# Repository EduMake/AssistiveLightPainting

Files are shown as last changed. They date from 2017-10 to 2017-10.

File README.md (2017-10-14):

# AssistiveLightPainting

Using SVG drawings to make light paintings using a custom large RGB light based non-orthongal plotter.

## Do you want to make videos like this ???

Lichtfactor - Talk Talk Advert (https://www.youtube.com/watch?v=QoT53RirX0Y)

## But physically moving a light quickly is difficult for you?

We are building a system to help. It will allow you to animate on your laptop and have a mechansism do the physical moving of the lights.

This uses the following technologies:-
 - Raspberry Pi
 - Adafruit Stepper Motor HAT https://www.adafruit.com/product/2348
 - SVG [Scalable Vector Graphics](https://en.wikipedia.org/wiki/Scalable_Vector_Graphics)
 - http://anigen.org/versions/0_8_1/
 - https://shop.pimoroni.com/products/mote
 - Out version of vPiP   https://github.com/EduMake/vPiP

## System Layout

You will prepare the animation and at shooting time set up a frame (we are prototyping with a 2.5m x 4m Chromakey background frame). Attach our vPlotter mounts, beaded cord and lights. 

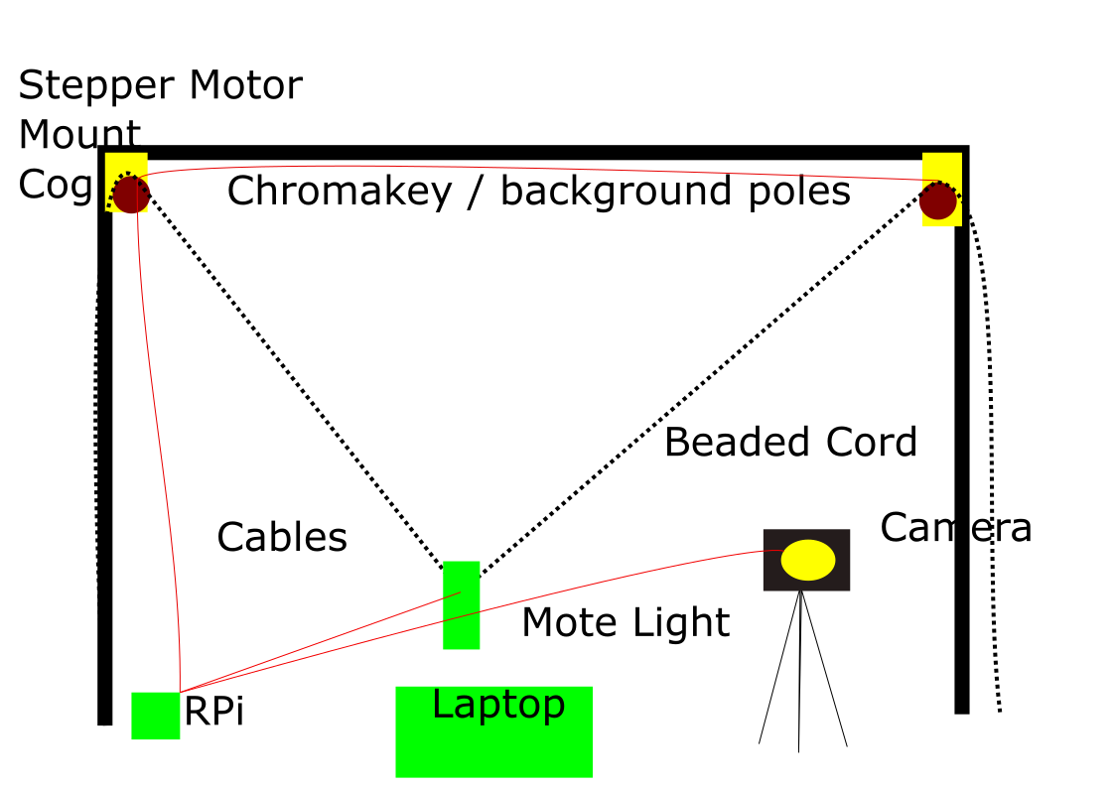
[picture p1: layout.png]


## Our custon vPlotter Mount

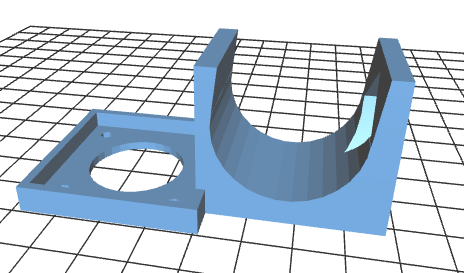
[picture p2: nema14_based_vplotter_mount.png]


### Currently in Development.

## The Proposed Process

- Install our software and hardware on a raspberry pi
- Use SVG editing software to draw your characters 
  - [inkscape](https://inkscape.org/en/) 
  - [SVG Edit](https://svg-edit.github.io/svgedit/releases/svg-edit-2.8.1/svg-editor.html)
  - [Vector Paint](http://vectorpaint.yaks.co.nz/)
  - [Drawing SVG](http://drawsvg.org/drawsvg.html)
- Use inkscape etc. to layout your scenes 
- Use Anigen to animate those scenes http://anigen.org/versions/0_8_1/
  - Line colours and widths should be picked up by the lights on the vplotter
- Export the animation as zip file of indvidual frames
- Set up our custom, large format light v-plotter, using our parts and a frame.
- Set up camera and raspberry pi control box
- Run through setup procedure in software
- Using your laptop / tablet / phone you will then trigger each frame to be lightpainted whilst the camera takes the shot
- The images are then compiled into a movie file.

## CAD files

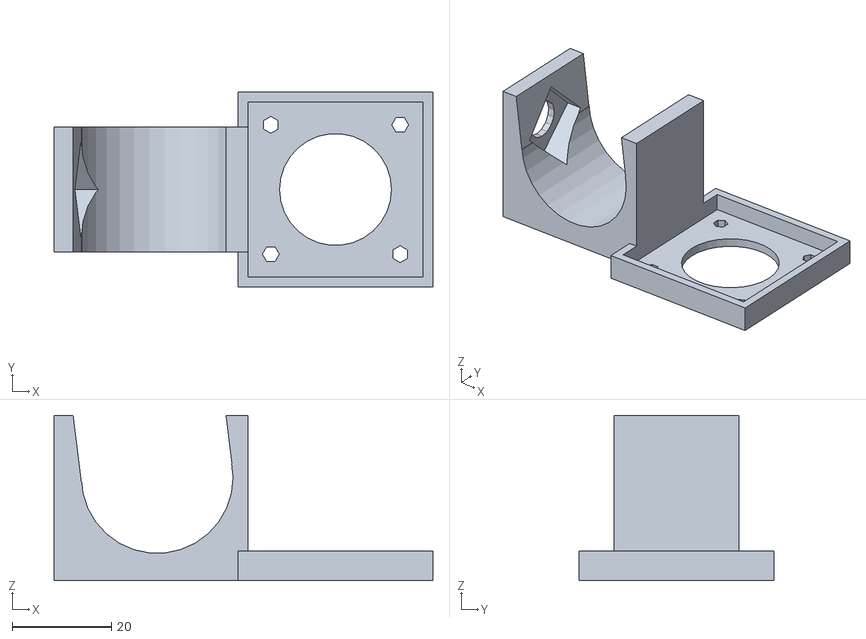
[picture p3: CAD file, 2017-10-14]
nema14_based_vplotter_mount.stl
76.2 x 39.2 x 33.2

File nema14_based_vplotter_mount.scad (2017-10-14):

//nema mount
nema_width      = 35.2;
nema_screw_dist = 26;
nema_screw_dia  = 3.4;
nema_indent_dia = 22.5;
plate_thickness = 2;
wall_height     = 6;

plate_width     = nema_width+(plate_thickness*2);
 
tube_dia        = 30.5;
clamp_inner      = 3;
clamp_outer      = 5.5;
nut_width = 13.5;
nut_depth = 3.5;
bolt_dia  = 9;


clamp_length     = (nut_width*sqrt(2))+(2*clamp_inner);//plate_width;
clamp_width = tube_dia+ clamp_inner + clamp_outer ;

clamp_height    = tube_dia+(clamp_outer*2);//clamp_width;//30;




union(){
    //nema plate
    translate([plate_width/2,0,wall_height/2]){
        difference(){
            
            cube([plate_width, plate_width, wall_height],center=true);
            
            translate([0,0,2]){
                cube([nema_width, nema_width,wall_height],center=true);
            }
            
            cylinder(r=nema_indent_dia/2,h=wall_height, center=true);
            
            
            for(angle = [0:90:300]){
                rotate(a = angle){
                    translate([nema_screw_dist/2,nema_screw_dist/2,0]){
                        cylinder(r=nema_screw_dia/2,h=wall_height, center=true);
                    }
                }
            }
        }
    }

    
    //clamp
    translate([plate_thickness -(clamp_width/2), 0, clamp_height/2]){
        
        difference(){        
            cube([clamp_width, clamp_length, clamp_height], center=true);
            translate([(clamp_outer-clamp_inner)/2,0,0]){
            rotate([90, 0, 0]){
                cylinder(r=tube_dia/2, h=plate_width, center=true);
            }
            
            rotate([0, -7, 0]){
            translate([0, 0, tube_dia*0.53]){
                
                    cube([tube_dia
                , clamp_width, tube_dia], center=true);
                }
            }
        
            //Captive nut
            translate([ -(tube_dia/2
        ), 0,0]){
                rotate([45,0,0]){
                    cube([nut_depth*2.2, nut_width,  nut_width], center=true);
                }
                rotate([0,90,0]){     
                    cylinder(r=bolt_dia/2,h=clamp_outer*3, center=true);
                }
            }
        }
            translate([0, 0, clamp_outer+(tube_dia/2)]){
                cube([clamp_width, clamp_height, clamp_outer*3], center=true);
            }
        
    }
    }
}

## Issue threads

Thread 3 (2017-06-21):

V-Plotter hardware

stretchyboy, 2017-06-21:
- http://homofaciens.de/technics-machines-v-plotter_en.htm
- http://www.open-electronics.org/how-to-make-an-opensource-vertical-plotter/
- http://polargraph.bigcartel.com/  especially the sprockets & beaded cord

Stepper Drivers

https://shop.pimoroni.com/products/adafruit-dc-stepper-motor-hat-for-raspberry-pi-mini-kit
https://shop.pimoroni.com/products/pistep2-quad-stepper-motor-control-board-for-raspberry-pi

stretchyboy, 2017-06-21:
- https://github.com/MarkJB/pi-zero-stepper-board

stretchyboy, 2017-06-21:
Motor mount and cog thing to modify to fit on the lighting poles https://www.thingiverse.com/thing:1393164

stretchyboy, 2017-06-21:
Lighting stand mount features

First, a 3/8-16 UNC thread (that's 3/8", 16 threads per inch). This is, fortunately, basically standardized in all such gear.

Second, a 5/8" stud, usually meant for clamping things to, or often attaching things via a socket with a screw on the side. This socket is often called a "receiver" or "receptor" — useful to know if you're searching.

Since the second connection type is less critical than matching threads, the precise size may vary — I've also often seem this described as a "16mm stud", which is very close to 5/8" but of course not identical. (And, yes, we're generally cavalier about mixing metric and imperial in photography — a so-called 1" sensor has a diagonal of 16mm, to pick another example.)

In many cases, the studs on light stands also are threaded on top. For example, here's the top of one of mine:

stretchyboy, 2017-07-26:
Motors are http://www.zappautomation.co.uk/sy35st36-1004b-high-torque-hybrid-stepper-motors.html

stretchyboy, 2017-08-16:
https://www.thingiverse.com/thing:569308

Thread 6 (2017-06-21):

Setup technique

stretchyboy, 2017-06-21:
a reproduce-able way to make sure the set up is the same each time.

maybe :
- zoom  out enough so the the poles are parallel at the edges of the shot
- position the light at the top right of the drawing area and zoom in until it's there in the view finder

Possible verification step using drawing the rule of thirds grid using the lights to line up against the one on the screen.

stretchyboy, 2017-06-21:
Ideal version of hardware would allow it to measure itself during setup. Possible by having the gondola start at the bottom height whilst the poles are together and have it draw the gondola up until it hits a limit switch. You would then run the gondola back down on both sides. Separate the 2 poles to the distance you want and hold on to them then run both motors until a limit switch shows its horizontal. then do maths.  That should give the total dimensions. use the code ideas in #5 . images are then either scaled to the draw area or rendered at actual size.

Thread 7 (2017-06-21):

Plotter software ideas

stretchyboy, 2017-06-21:
- https://github.com/bertlr/vplotter
- https://github.com/brianinnes/vpip  https://www.makebournemouth.com/?p=947
- http://plotterbot.com/robots/plotterbot-documentation/plotterbot-prior-art/ list of projects

stretchyboy, 2017-07-27:
Most likely appears to be  https://github.com/brianinnes/vPiP

If I fork it and replace the serialHandler with one that handles the stepper hat  https://shop.pimoroni.com/products/adafruit-dc-stepper-motor-hat-for-raspberry-pi-mini-kit

And a the light and possibly camera control :)

stretchyboy, 2017-08-23:
sudo pip install webcolors

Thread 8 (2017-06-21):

Identify minimum test rig.

stretchyboy, 2017-06-21:
- [ ] get motors
- [ ] find stepper driver board
- [ ] could we mount motors with gaffer tape?
- [ ] 3d print gears to fit the motors.
- [ ] Get cord
- [ ] Mount torch or mote in middle of cord
- [ ] get driver  software just to do up & down on both motors
- [ ] Test with camera

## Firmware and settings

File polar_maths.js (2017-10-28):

var extend = require('extend');
var queue = require('queue');
var promiseify = require('promiseify');

//extend(targetObject, object1, object2);

/*can be set to calc drawing and offset  using ideas from
http://2e5.com/plotter/V/design/ so set machine size and
tell it the aspectratio (that of the camera) and it will
 maximise the effective working area
aspect_ratio :  16/9 */

var PolarMaths = module.exports = function PolarMaths(options) {
  this.q = queue({
    concurrency: 1,
    autostart: true
  });
  this.q.on('success', function(result, job) {
    //console.log('job finished processing:', job.toString().replace(/\n/g, ''))
  });

  options = options || {};

  this.dimensions_mm = {
    machine: {
      x: 4000,
      y: 2000
    },
    drawing: {
      x: 2000,
      y: 1200
    },
    offset: {
      x: 1000,
      y: 400
    },
    wheel_circumference: 94.25,
    min_move: 1
  };
  this.steps_per_rev = 200;
  this.image_size = {
    x: 600,
    y: 400
  };
  this.steps_per_sec = 200;
  this.motor_directions = {
    l: 1,
    r: -1
  }
  this.live = false;


  extend(true, this, options);

  if (this.live) {
    this.motorHat = require('motor-hat')({
      steppers: [{
        W1: 'M1',
        W2: 'M2'
      }]
    }).init();


    this.motors = {
      left: this.motorHat.steppers[0],
      right: this.motorHat.steppers[1]
    };
    this.motors.l.setSpeed({
      sps: this.steps_per_sec
    });
    this.motors.r.setSpeed({
      sps: this.steps_per_sec
    });
    this.motors.l.stepP = promiseify(this.motors.l.step);
    this.motors.r.stepP = promiseify(this.motors.r.step);
  }
};

PolarMaths.prototype.setup_machine = function() {
  //console.log("org", this);
  this.machine_pos = {
    x: 0,
    y: this.dimensions_mm.machine.y
  };
  this.steps_per_mm = this.steps_per_rev / this.dimensions_mm.wheel_circumference;
  this.pixel_mm = {
    x: this.dimensions_mm.drawing.x / this.image_size.x,
    y: this.dimensions_mm.drawing.y / this.image_size.y
  };

  console.log("after", this);
  this.steps_pos = this.get_steps_pos(this.machine_pos);
  //console.log("steps", this.steps_pos);

};

PolarMaths.prototype.get_machine_pos = function(drawing) {
  var mac = {
    x: (drawing.x * this.pixel_mm.x) + this.dimensions_mm.offset.x,
    y: (drawing.y * this.pixel_mm.y) + this.dimensions_mm.offset.y
  };
  console.log("get_machine_pos drawing", drawing, "mac", mac);
  return mac;
};

PolarMaths.prototype.start_machine = function() {
  var drawing_start = {
    x: 0,
    y: this.image_size.y
  };
  this.move_to(drawing_start);
};

PolarMaths.prototype.getDelta = function(posA, posB) {
  var delta = {
    l: posB.l - posA.l,
    r: posB.r - posA.r
  };
  return delta;
};

PolarMaths.prototype.getDeltaMM = function(posA, posB) {
  var delta = {
    x: posB.x - posA.x,
    y: posB.y - posA.y
  };
  return delta;
};

PolarMaths.prototype.start_steps = function(motor, delta) {
  var dir = "fwd";
  delta = delta * this.motor_directions[motor];
  if (delta < 0) {
    dir = "back";
  }
  var steps = Math.abs(delta);
  if (steps == 0 || !this.live) {
    return new Promise((resolve, reject) => {
      resolve({
        motor: motor,
        dir: dir,
        steps: steps,
        duration: 0,
        retried: 0
      });
    });
  }
  return this.motors.l.stepP(dir, steps);
};

//Add coords to a queue,
PolarMaths.prototype.end_step = function(results) {
  ////console.log("end_step", results);
  results.forEach(function(result) {
    //console.log(`${result.motor} did ${result.steps} steps ${result.dir} in ${result.duration/1000} seconds. I had to retry ${result.retried} steps.`);
  });
};

PolarMaths.prototype.fail_step = function(err) {
  if (err) {
    return console.log('Oh no, there was an error', err);
  }
};

PolarMaths.prototype.move_to = function(coord) {
  console.log("move_to", coord);
  var new_pos = this.get_steps_from_drawing(coord);
  var steps_delta = this.getDelta(this.steps_pos, new_pos);
  var job = function() {
    return Promise.all([
      this.start_steps("l", steps_delta.l),
      this.start_steps("r", steps_delta.r)
    ]).then(this.end_step).catch(this.fail_step);
  };

  this.q.push(job.bind(this));

  this.steps_pos = new_pos;
  this.draw_pos = coord;
  console.log("move_to draw_pos", this.draw_pos ,"steps_pos", this.steps_pos, "steps_delta", steps_delta);

};


PolarMaths.prototype.draw_to = function(coord) {
  console.log("draw_to", coord);
  /*//turn light on as promise or callback
  just a http call to the other server.
    */

  var curr_pos = {
    x: this.draw_pos.x,
    y: this.draw_pos.y
  };
  var drawing_delta = this.getDeltaMM(curr_pos, coord);
  var biggest = Math.floor(
    Math.max(Math.abs(drawing_delta.x), Math.abs(drawing_delta.y)) / this.dimensions_mm.min_move
  );
  console.log("draw_to drawing_delta", drawing_delta, " biggest", biggest);

  if (biggest) {
    for (var i = 1; i <= biggest; i++) {
      var point = curr_pos;
      point.x = point.x + ((drawing_delta.x / biggest) * i);
      point.y = point.y + ((drawing_delta.y / biggest) * i);
      this.move_to(point);
    }
  }
  /*//turn light off as Promise
  this.q.push(
    new Promise
    */

  this.draw_pos = coord;
};


PolarMaths.prototype.get_steps_from_drawing = function(drawing) {
  //console.log("get_steps_from_drawing drawing", drawing);
  return this.get_steps_pos(this.get_machine_pos(drawing));
};

PolarMaths.prototype.steps_from_mm = function(mm) {
  //console.log("steps_from_mm", mm);
  return Math.round(mm * this.steps_per_mm);
};
//Should be able to get drawing size from machine size and image dimensions

//Get to start pos (bottom left of image?)
PolarMaths.prototype.get_steps_pos = function(machine) {
  var steps = {
    l: this.steps_from_mm(Math.sqrt((machine.x * machine.x) + (machine.y * machine.y))),
    r: this.steps_from_mm(Math.sqrt(((this.dimensions_mm.machine.x - machine.x) * (this.dimensions_mm.machine.x - machine.x)) + (machine.y * machine.y)))
  };
  //console.log("get_steps_pos machine", machine, "steps", steps);
  return steps;
};

var oPolarMaths = new PolarMaths();
oPolarMaths.setup_machine();
oPolarMaths.start_machine();

oPolarMaths.move_to({
  x: 100,
  y: 100
});
oPolarMaths.draw_to({
  x: 200,
  y: 100,
  color: {
    r: 255,
    g: 0,
    b: 0
  },
  width: 1
});
oPolarMaths.draw_to({
  x: 200,
  y: 200,
  color: {
    r: 0,
    g: 255,
    b: 0
  },
  width: 2
});
oPolarMaths.draw_to({
  x: 100,
  y: 200,
  color: {
    r: 0,
    g: 0,
    b: 255
  },
  width: 3
});
oPolarMaths.draw_to({
  x: 100,
  y: 100,
  color: {
    r: 255,
    g: 255,
    b: 0
  },
  width: 4
});
oPolarMaths.move_to({
  x: 0,
  y: 0
});
//console.log(oPolarMaths.get_steps_pos());

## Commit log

2017-07-26 First draft of pole gripping nema 14 holder
    Working toward #3 . Parameters for nut size, wall thickness etc need reviewing one the nut turn up.
    https://www.amazon.co.uk/dp/B00AR0BNRC/
    https://www.amazon.co.uk/dp/B073372TQP/
    [nema14_based_vplotter.scad, nema14_based_vplotter.stl]
2017-08-04 Real Nut size
    [nema14_based_vplotter.scad, nema14_based_vplotter.stl]
